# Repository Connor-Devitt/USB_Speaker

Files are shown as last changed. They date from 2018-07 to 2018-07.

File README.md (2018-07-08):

# USB_Speaker
Electro-mechanical design for a  USB spaker

## Electrical Design
* Designed for single cable operation
* USB powered with on-board USB to audio DAC and stereo audio amplifier
* 2 18650 batteries for high power amplifier
* USB charges batteries when speaker is idle

### The Schematic (v0.1)
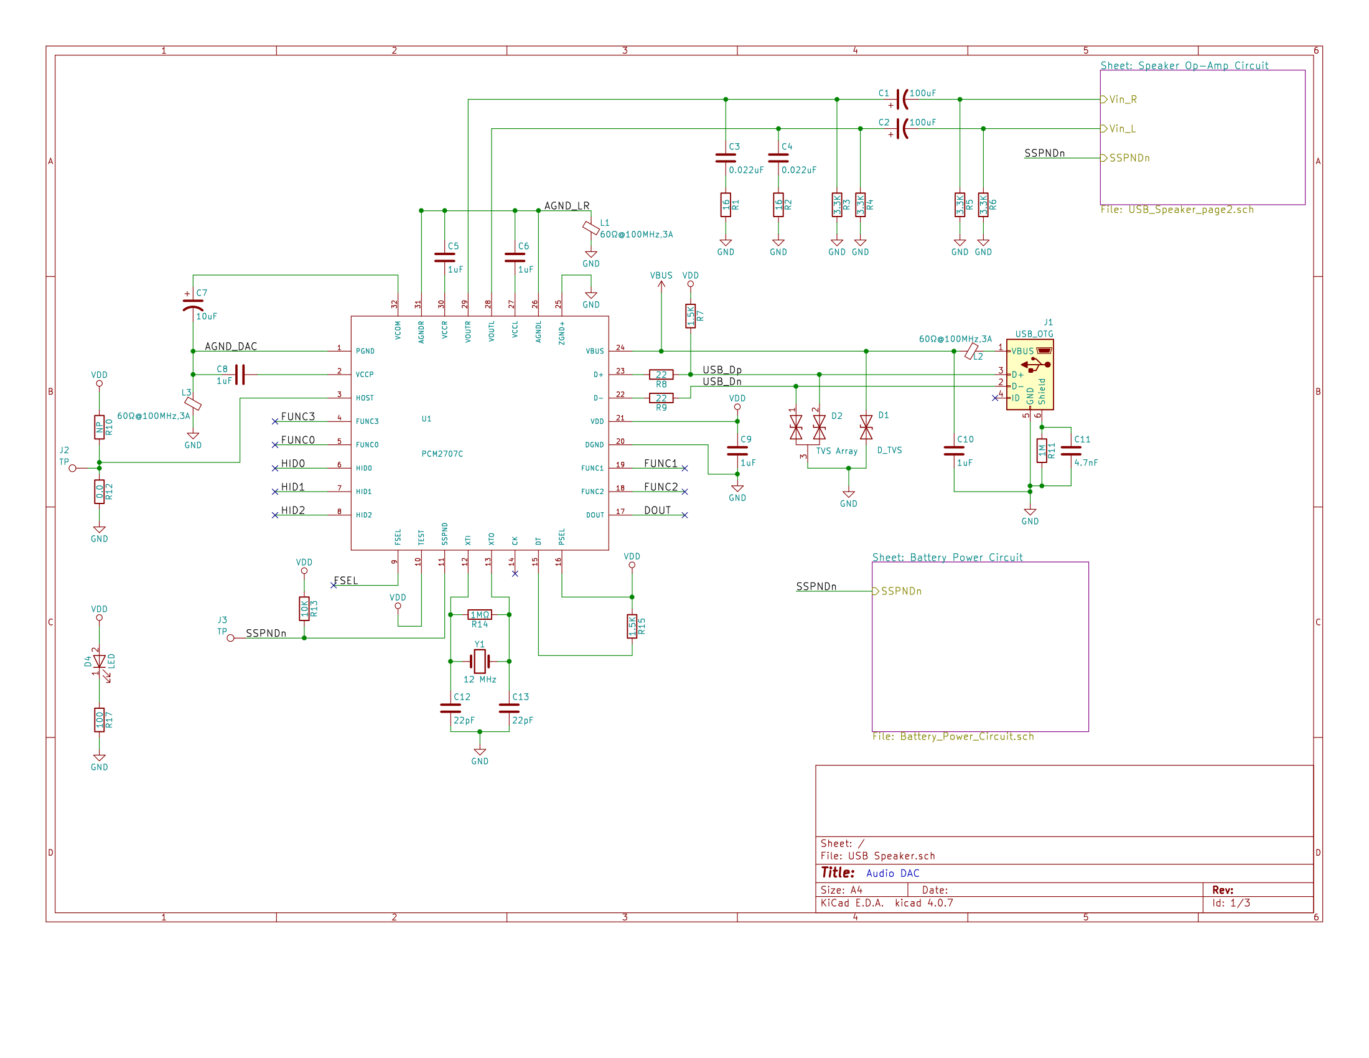
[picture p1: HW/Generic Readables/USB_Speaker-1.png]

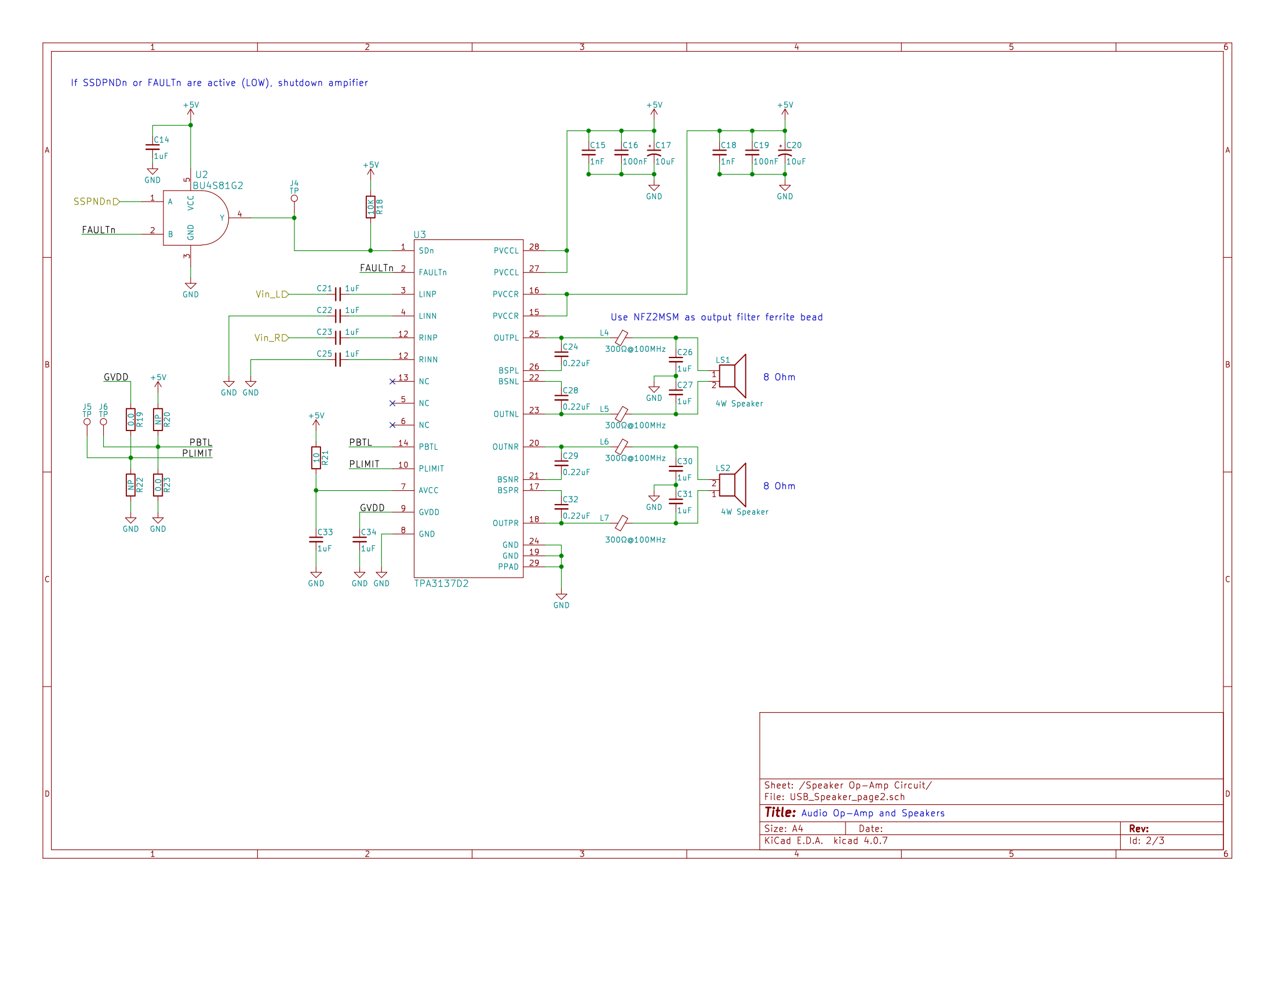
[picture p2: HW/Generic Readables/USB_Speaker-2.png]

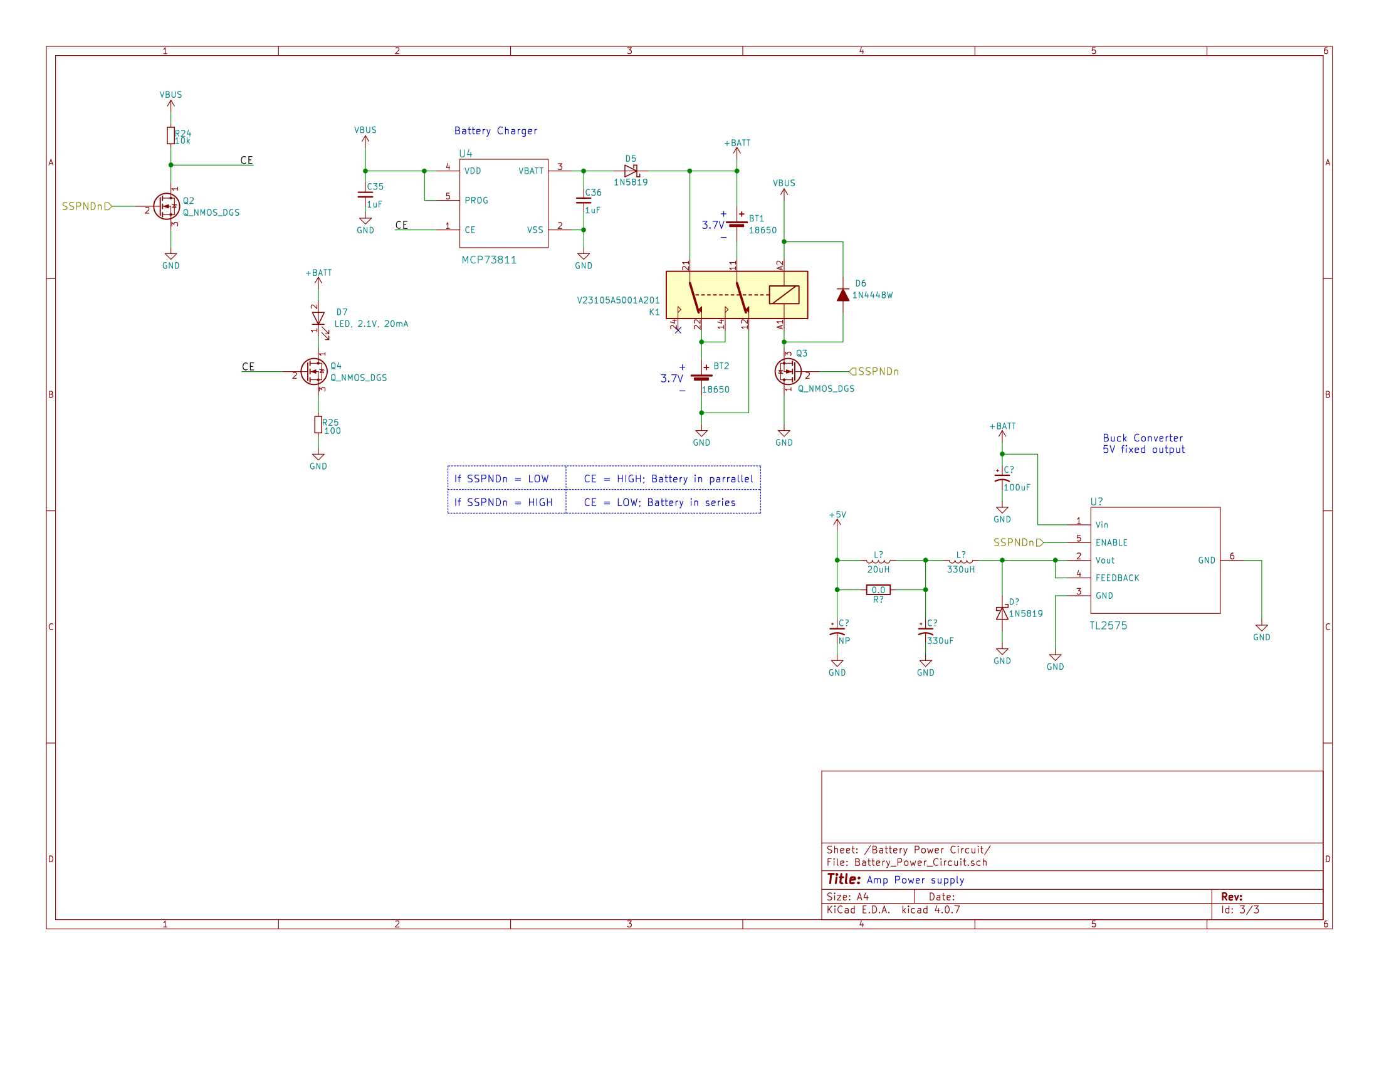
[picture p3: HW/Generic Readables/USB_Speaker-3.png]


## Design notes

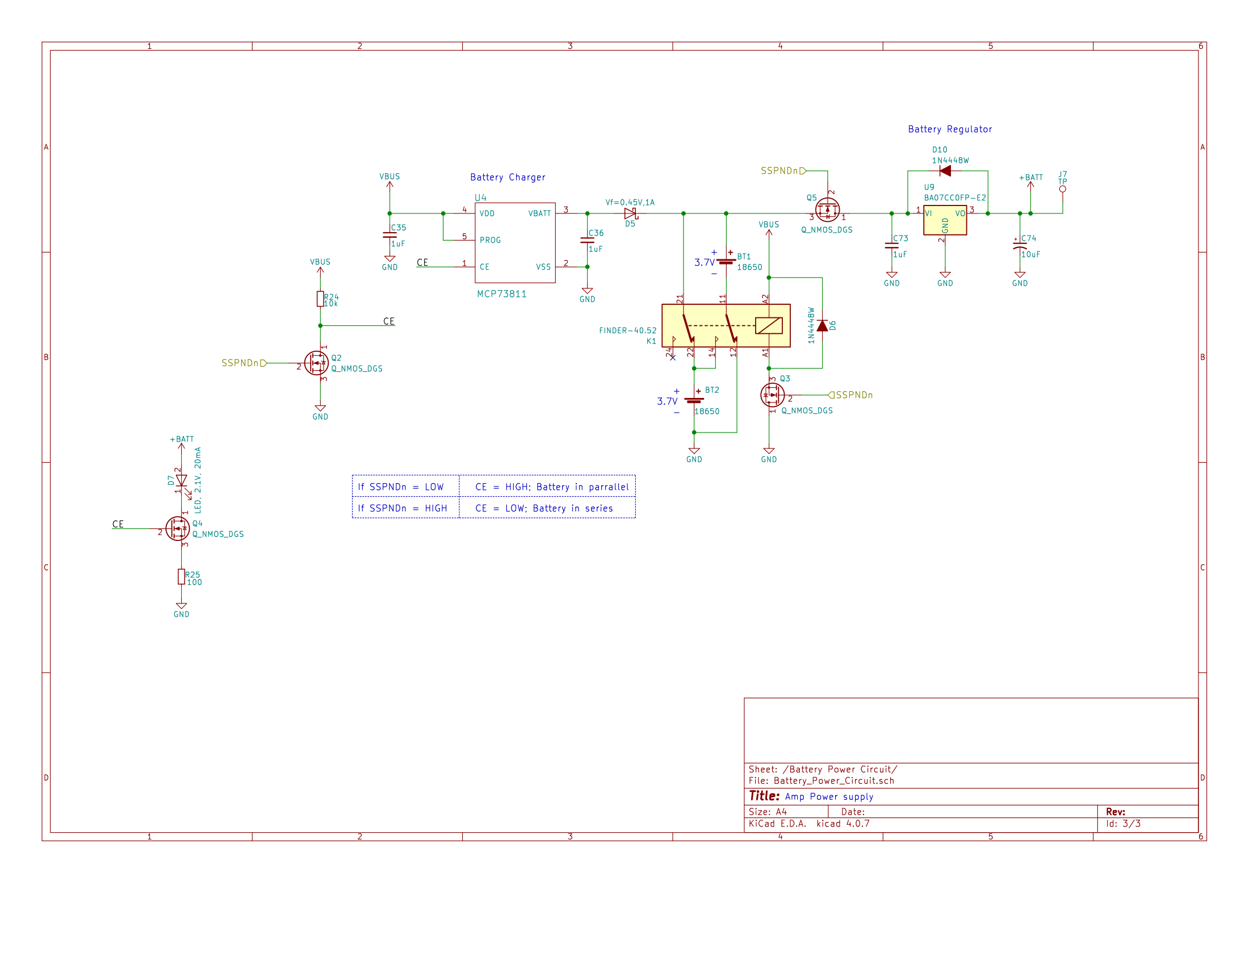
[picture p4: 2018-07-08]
HW/USB_Speaker-3.png

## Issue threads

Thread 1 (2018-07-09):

Battery Saftey

Connor-Devitt, 2018-07-09:
Add over current protection to lipo battery supply

Connor-Devitt, 2018-07-10:
Clarification: Add current monitor IC to *input* of LM2576 and tie output to enable of LM2576.

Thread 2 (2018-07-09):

Power consumption

Connor-Devitt, 2018-07-09:
Change battery regulator to 5V buck converter. Run amplifier off 5V not 7V and use 8-ohm speakers to limit power consumption.

Connor-Devitt, 2018-07-10:
Done.

Closed 2018-07-10.

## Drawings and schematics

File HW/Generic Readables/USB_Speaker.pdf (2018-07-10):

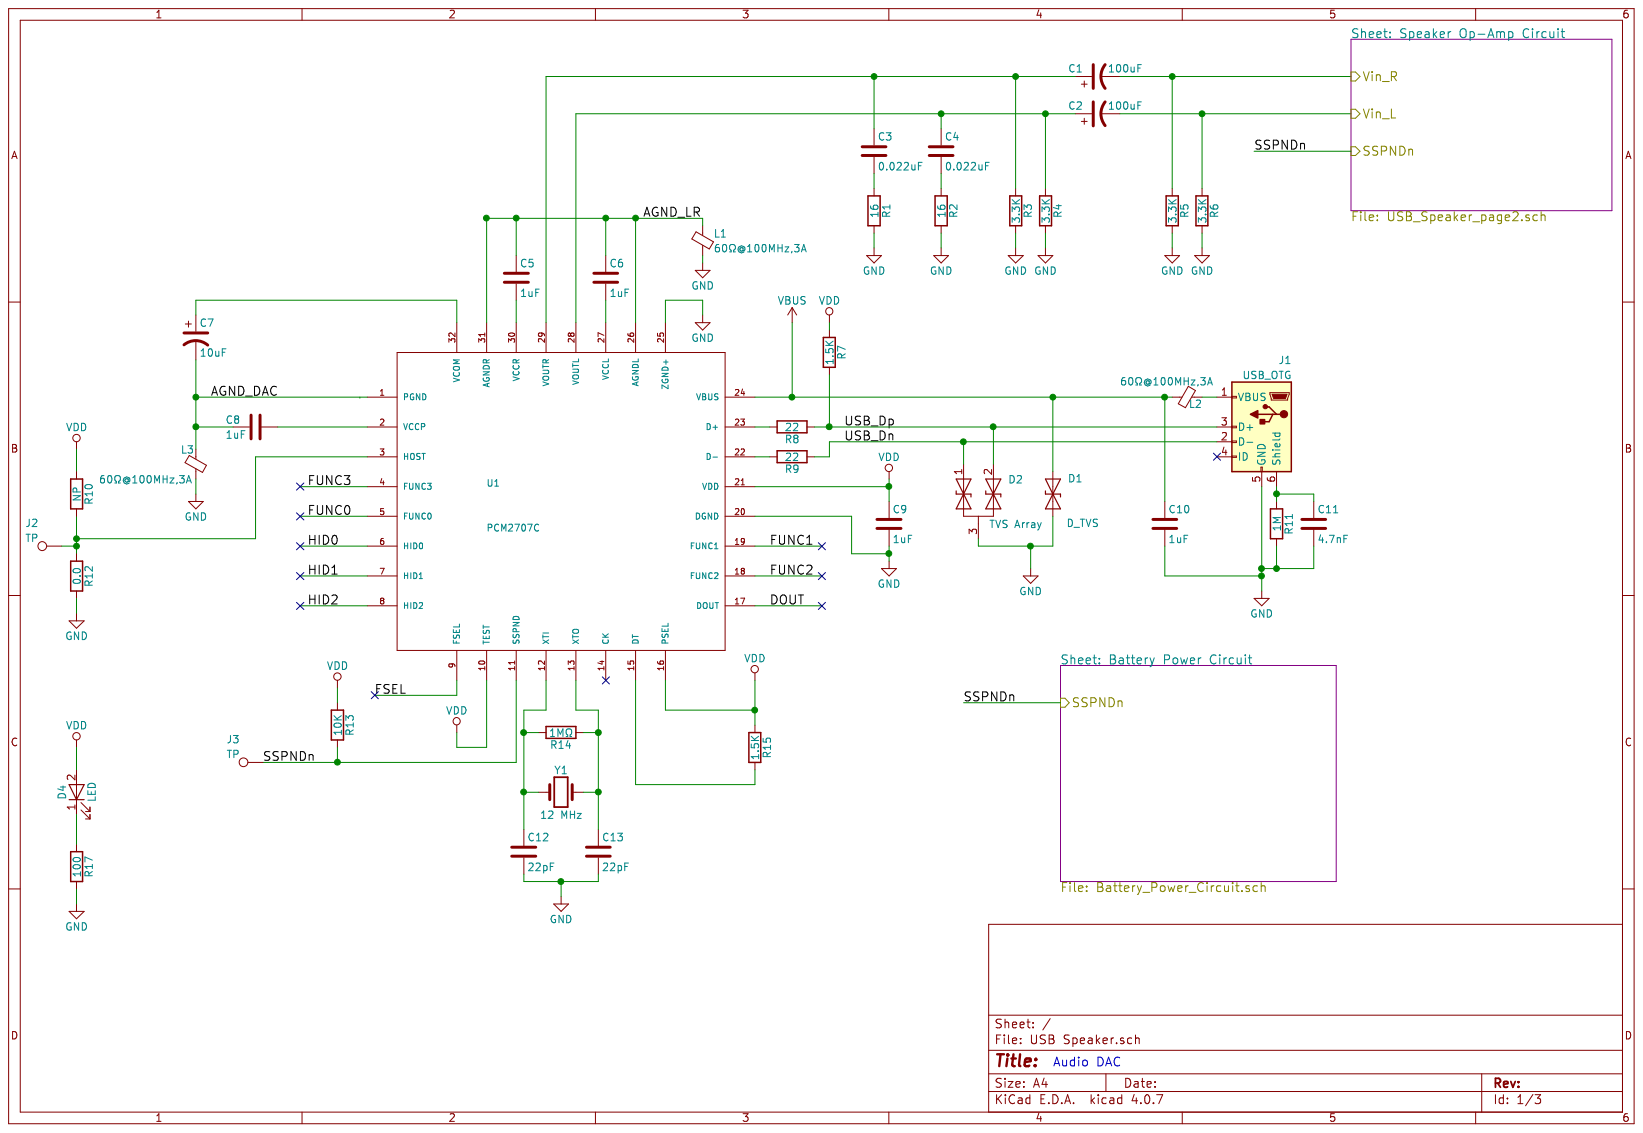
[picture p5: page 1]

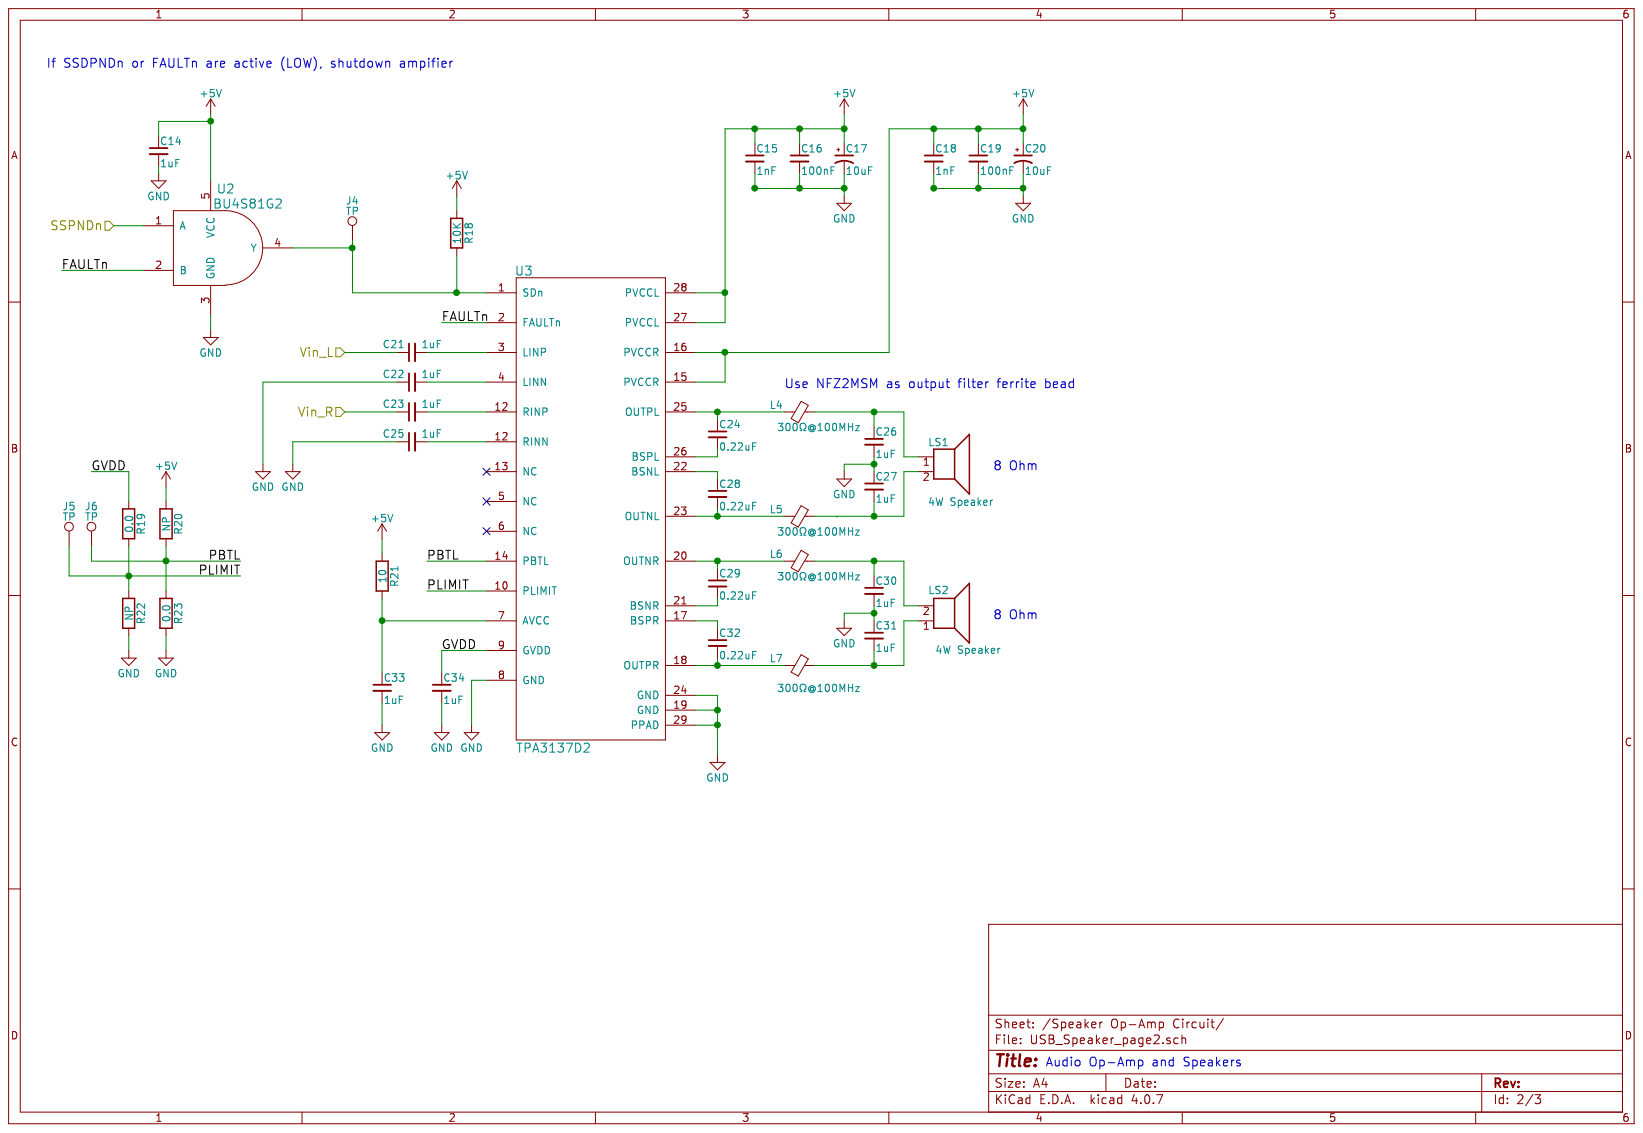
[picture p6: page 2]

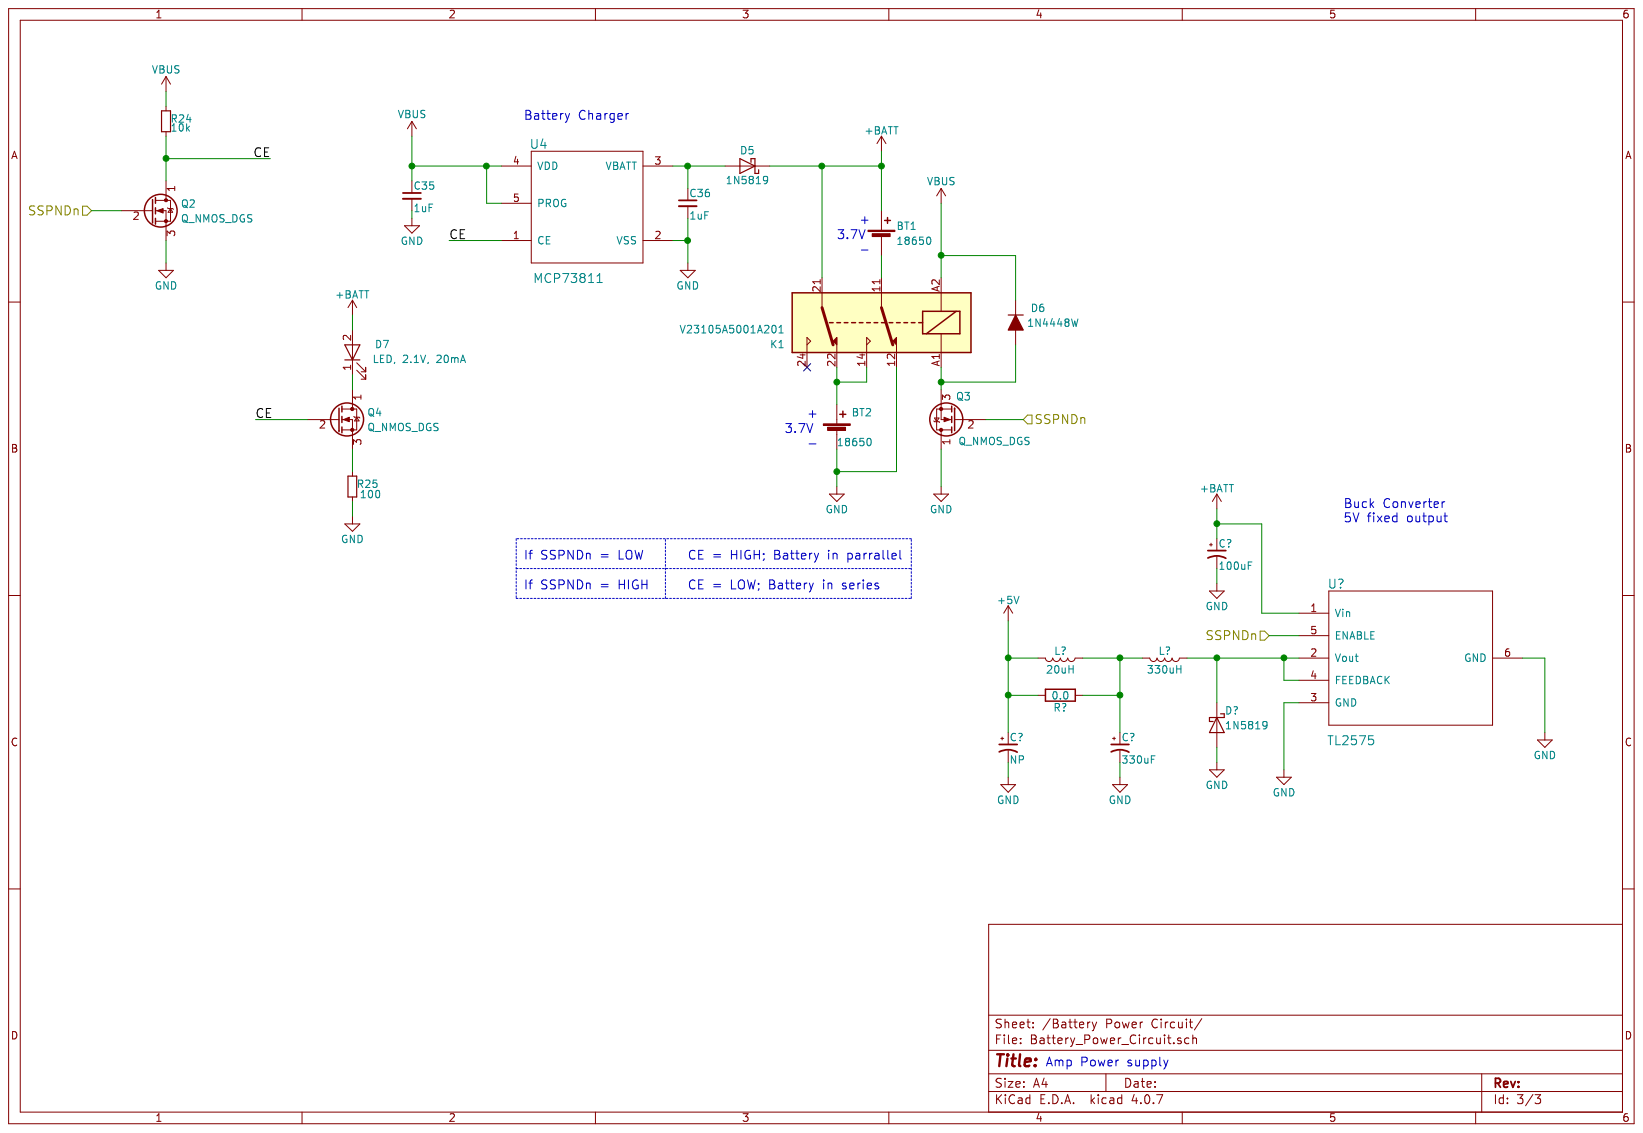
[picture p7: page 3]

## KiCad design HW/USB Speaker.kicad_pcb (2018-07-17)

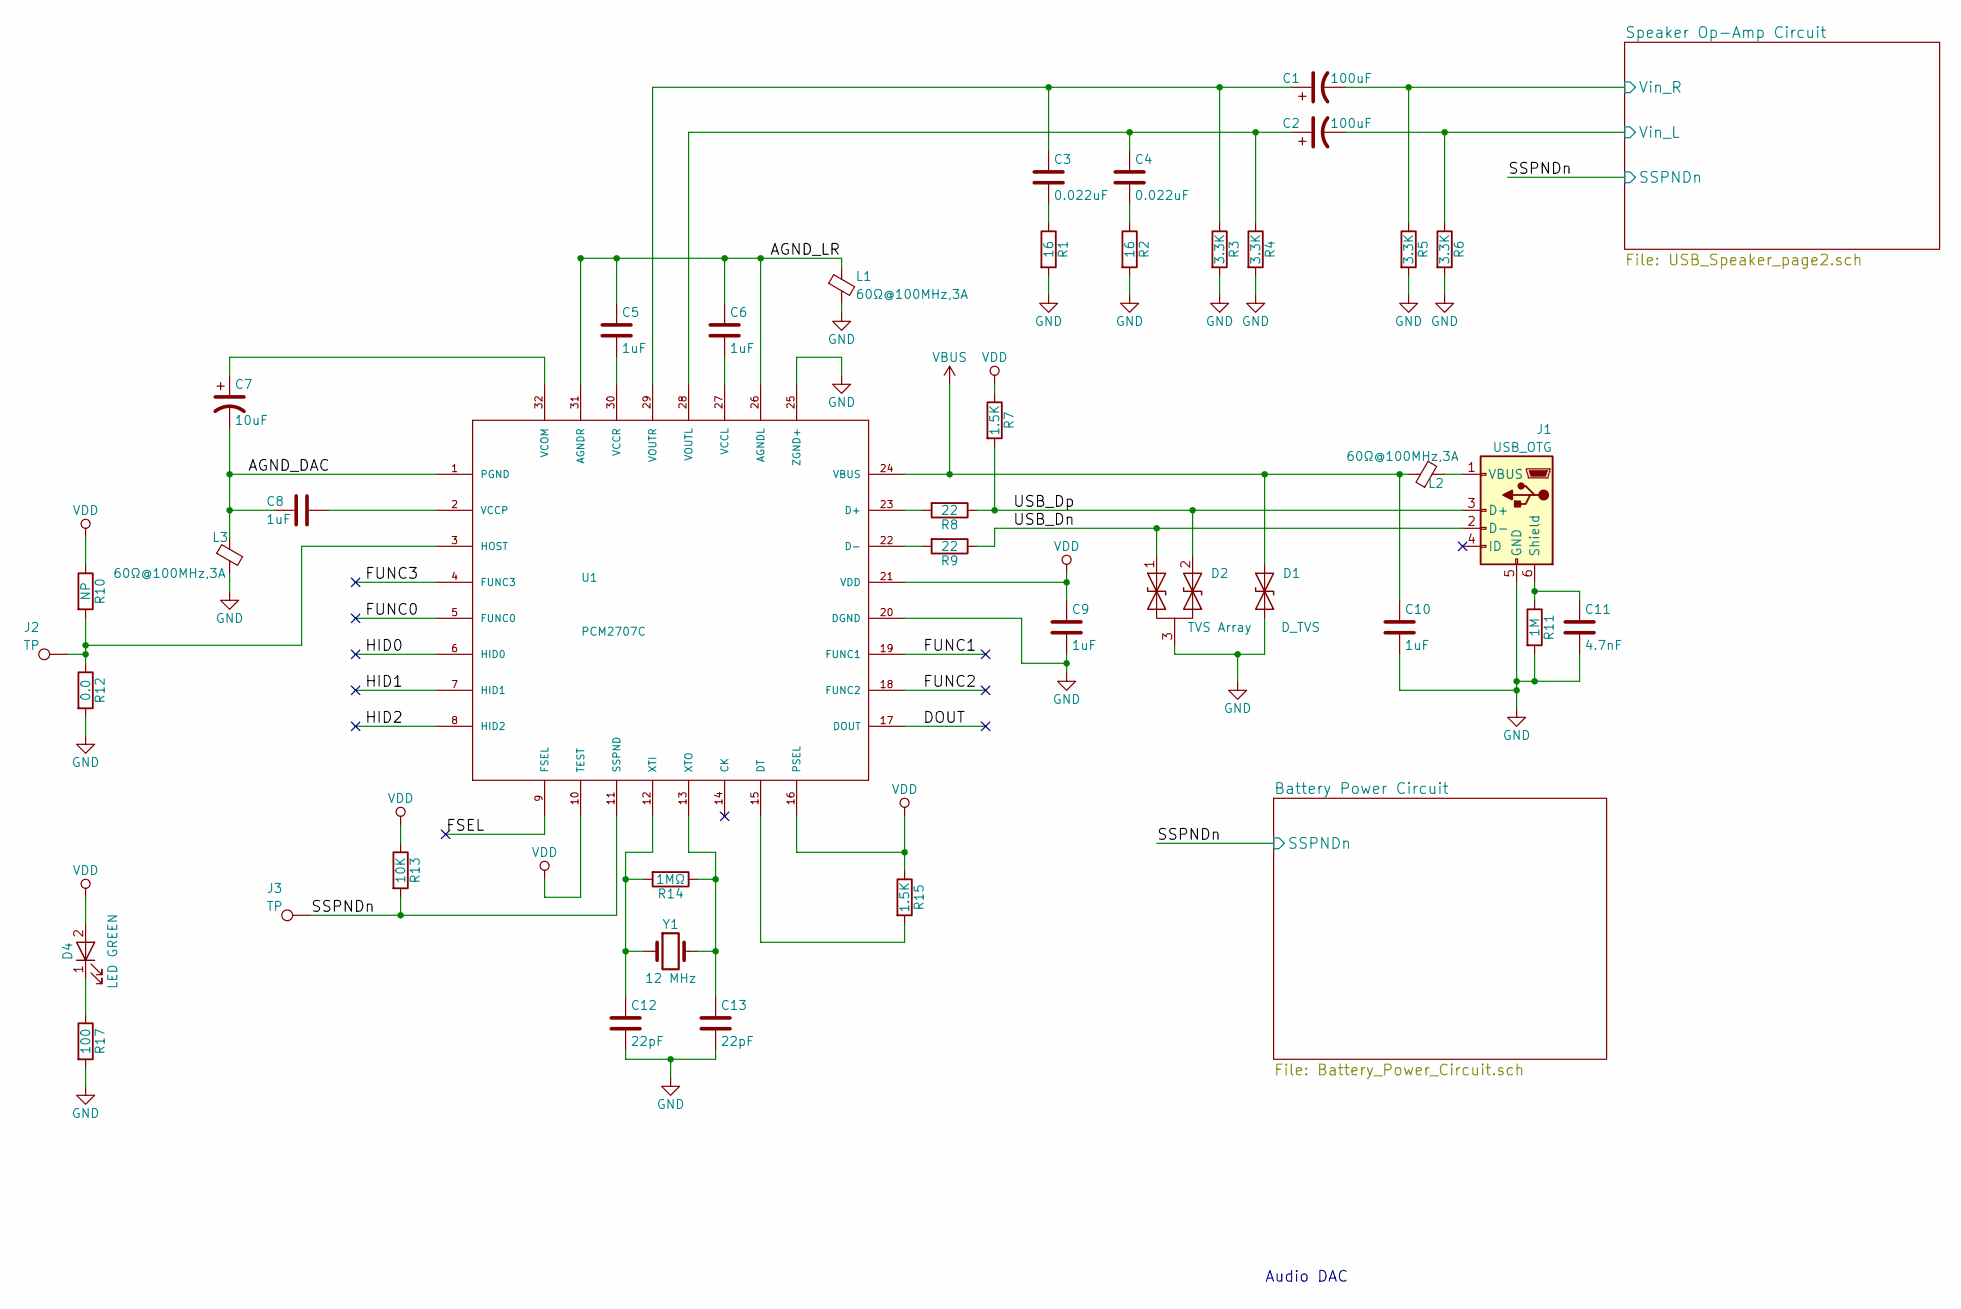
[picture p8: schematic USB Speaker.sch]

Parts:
C1, C2: 100uF; CP_Elec_6.3x5.7
C3, C4: 0.022uF; C_0805_HandSoldering
C5, C6, C8, C9, C10: 1uF; C_0805_HandSoldering
C7: 10uF; CP_Elec_6.3x5.7
C11: 4.7nF; C_0805_HandSoldering
C12, C13: 22pF; C_0805_HandSoldering
D1: D_TVS; D_SC79
D2: TVS Array; SOT-23
D4: LED GREEN; D_0805
J1: USB_OTG; USB_miniB_hirose_5S8
J2, J3: TP; Measurement_Point_Round-TH_Big
L1, L2, L3: 60Ω@100MHz,3A; L_0805_HandSoldering
R1, R2: 16; R_0805_HandSoldering
R3, R4, R5, R6: 3.3K; R_0805_HandSoldering
R7, R15: 1.5K; R_0805_HandSoldering
R8, R9: 22; R_0805_HandSoldering
R10: NP; R_0805_HandSoldering
R11: 1M; R_0805_HandSoldering
R12: 0.0; R_0805_HandSoldering
R13: 10K; R_0805_HandSoldering
R14: 1MΩ; R_0805_HandSoldering
R17: 100; R_0805_HandSoldering
U1: PCM2707C; TQFP-32_7x7mm_Pitch0.8mm
Y1: 12 MHz; Crystal_HC49-4H_Vertical

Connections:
/AGND_DAC: C7.2, C8.2, L3.1, U1.1 (PGND)
/AGND_LR: C5.1, C6.1, L1.1, U1.26 (AGNDL), U1.31 (AGNDR)
/DOUT: U1.17 (DOUT)
/FSEL: U1.9 (FSEL)
/FUNC0: U1.5 (FUNC0)
/FUNC1: U1.19 (FUNC1)
/FUNC2: U1.18 (FUNC2)
/FUNC3: U1.4 (FUNC3)
/HID0: U1.6 (HID0)
/HID1: U1.7 (HID1)
/HID2: U1.8 (HID2)
/SSPNDn: J3.1, R13.2, U1.11 (SSPND); also elsewhere on the board
/Speaker Op-Amp Circuit/Vin_L: C2.2, R6.1; also elsewhere on the board
/Speaker Op-Amp Circuit/Vin_R: C1.2, R5.1; also elsewhere on the board
/USB_Dn: D2.1 (A1), J1.2 (D-), R9.1
/USB_Dp: D2.2 (A2), J1.3 (D+), R7.2, R8.1
GND: C9.2, C10.2, C11.2, C12.2, C13.2, D1.1 (A1), D2.3 (common), J1.5 (GND), L1.2, L3.2, R1.2, R2.2, R3.2, R4.2, R5.2, R6.2, R11.2, R12.2, R17.2, U1.20 (DGND), U1.25 (ZGND+); also elsewhere on the board
unnamed: C1.1, C3.1, R3.1, U1.29 (VOUTR)
unnamed: C2.1, C4.1, R4.1, U1.28 (VOUTL)
unnamed: C3.2, R1.1
unnamed: C4.2, R2.1
unnamed: C5.2, U1.30 (VCCR)
unnamed: C6.2, U1.27 (VCCL)
unnamed: C7.1, U1.32 (VCOM)
unnamed: C8.1, U1.2 (VCCP)
unnamed: C11.1, J1.6 (Shield), R11.1
unnamed: C12.1, R14.2, U1.12 (XTI), Y1.1
unnamed: C13.1, R14.1, U1.13 (XTO), Y1.2
unnamed: D4.1 (K), R17.1
unnamed: J1.1 (VBUS), L2.2
unnamed: J2.1, R10.2, R12.1, U1.3 (HOST)
unnamed: R8.2, U1.23 (D+)
unnamed: R9.2, U1.22 (D-)
unnamed: R15.2, U1.15 (DT)
VBUS: C10.1, D1.2 (A2), L2.1, U1.24 (VBUS); also elsewhere on the board
VDD: C9.1, D4.2 (A), R7.1, R10.1, R13.1, R15.1, U1.10 (TEST), U1.16 (PSEL), U1.21 (VDD)

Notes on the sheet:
Audio DAC

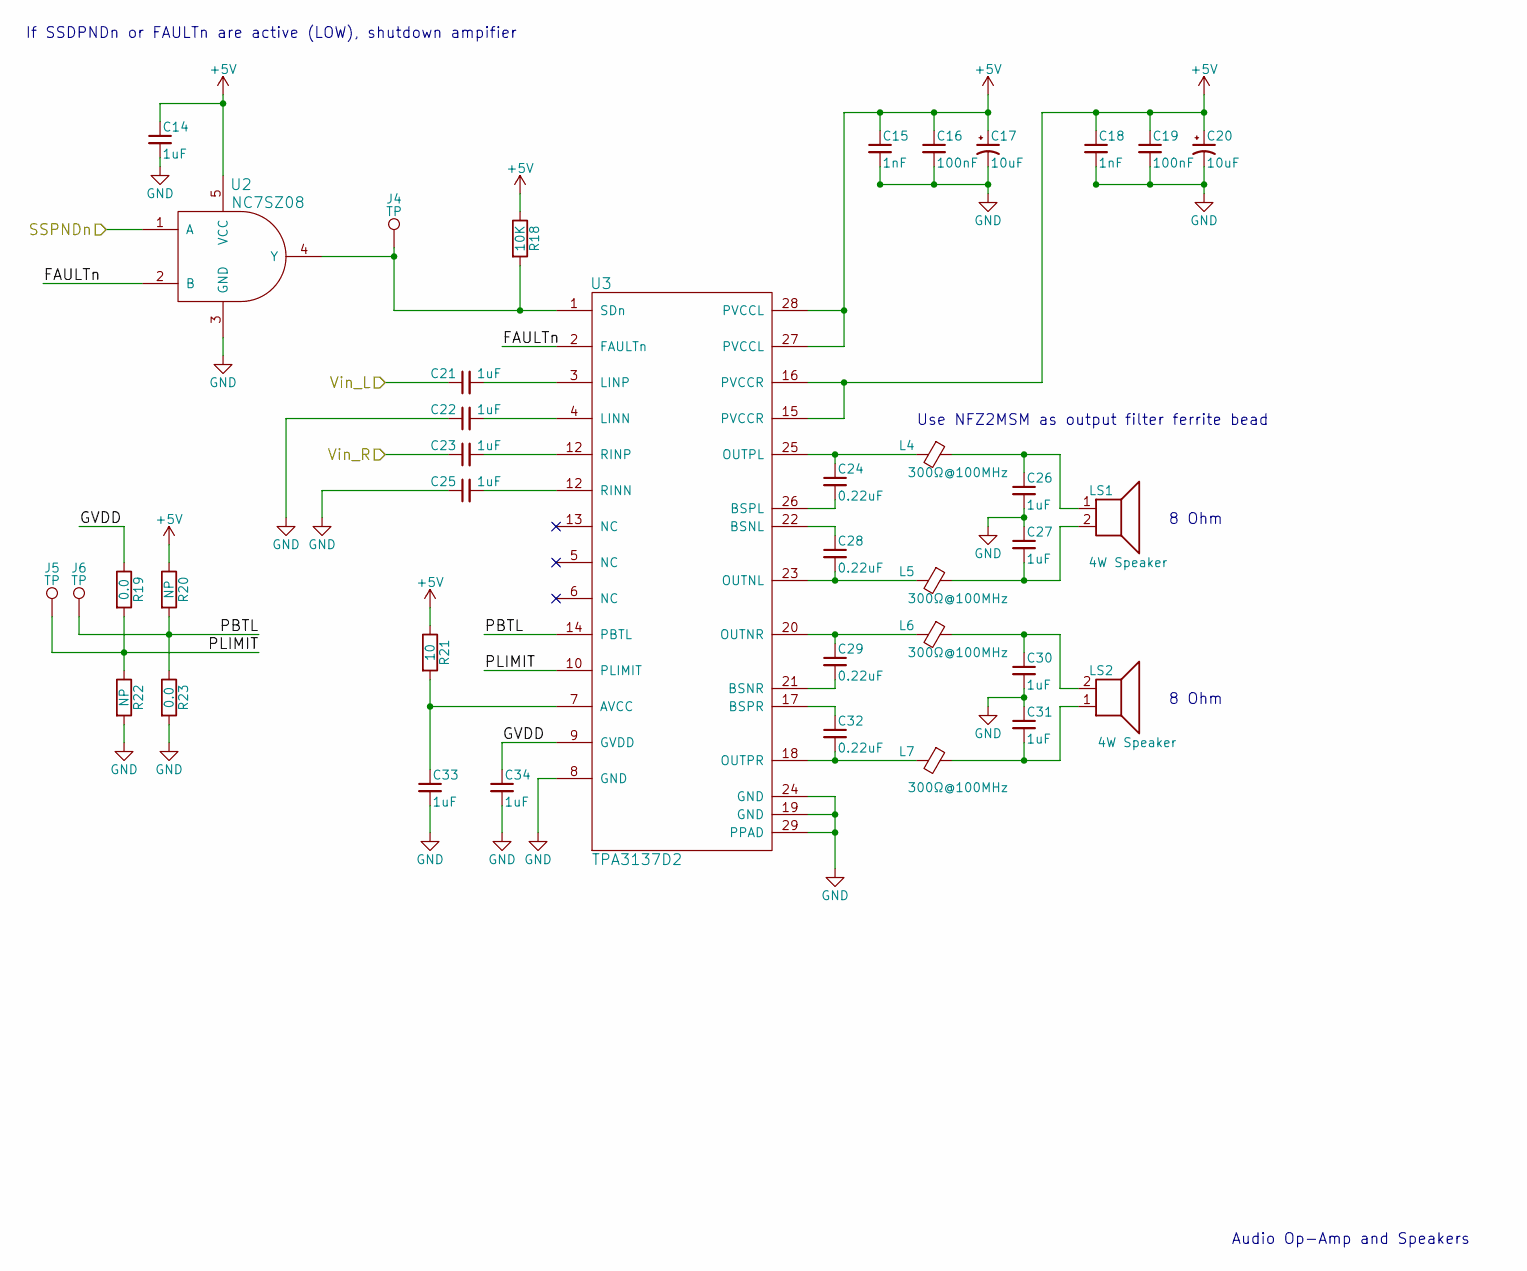
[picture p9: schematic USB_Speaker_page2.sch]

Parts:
C14, C21, C22, C23, C25, C26, C27, C30, C31, C33, C34: 1uF; C_0805_HandSoldering
C15, C18: 1nF; C_0805_HandSoldering
C16, C19: 100nF; C_0805_HandSoldering
C17, C20: 10uF; CP_Elec_6.3x5.7
C24, C28, C29, C32: 0.22uF; C_0805_HandSoldering
J4, J5, J6: TP; Measurement_Point_Round-TH_Big
L4, L5, L6, L7: 300Ω@100MHz; L_0805_HandSoldering
LS1, LS2: 4W Speaker; TerminalBlock_bornier-2_P5.08mm
R18: 10K; R_0805_HandSoldering
R19, R23: 0.0; R_0805_HandSoldering
R20, R22: NP; R_0805_HandSoldering
R21: 10; R_0805_HandSoldering
U2: NC7SZ08; SOT-23-5_HandSoldering
U3: TPA3137D2; TSSOP-28_4.4x9.7mm_Pitch0.65mm

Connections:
+5V: C14.1, C15.1, C16.1, C17.1, C18.1, C19.1, C20.1, R18.1, R20.1, R21.1, U2.5 (VCC), U3.15 (PVCCR), U3.16 (PVCCR), U3.27 (PVCCL), U3.28 (PVCCL); also elsewhere on the board
/SSPNDn: U2.1 (A); also elsewhere on the board
/Speaker Op-Amp Circuit/FAULTn: U2.2 (B), U3.2 (FAULTn)
/Speaker Op-Amp Circuit/GVDD: C34.1, R19.1, U3.9 (GVDD)
/Speaker Op-Amp Circuit/PBTL: J6.1, R20.2, R23.1, U3.14 (PBTL)
/Speaker Op-Amp Circuit/PLIMIT: J5.1, R19.2, R22.1, U3.10 (PLIMIT)
/Speaker Op-Amp Circuit/Vin_L: C21.1; also elsewhere on the board
/Speaker Op-Amp Circuit/Vin_R: C23.1; also elsewhere on the board
GND: C14.2, C15.2, C16.2, C17.2, C18.2, C19.2, C20.2, C22.1, C25.1, C26.2, C27.1, C30.2, C31.1, C33.2, C34.2, R22.2, R23.2, U2.3 (GND), U3.8 (GND), U3.19 (GND), U3.24 (GND), U3.29 (PPAD); also elsewhere on the board
unnamed: C21.2, U3.3 (LINP)
unnamed: C22.2, U3.4 (LINN)
unnamed: C24.1, L4.2, U3.25 (OUTPL)
unnamed: C24.2, U3.26 (BSPL)
unnamed: C26.1, L4.1, LS1.1
unnamed: C27.2, L5.1, LS1.2
unnamed: C28.1, U3.22 (BSNL)
unnamed: C28.2, L5.2, U3.23 (OUTNL)
unnamed: C29.1, L6.2, U3.20 (OUTNR)
unnamed: C29.2, U3.21 (BSNR)
unnamed: C30.1, L6.1, LS2.2
unnamed: C31.2, L7.1, LS2.1
unnamed: C32.1, U3.17 (BSPR)
unnamed: C32.2, L7.2, U3.18 (OUTPR)
unnamed: C33.1, R21.2, U3.7 (AVCC)
unnamed: J4.1, R18.2, U2.4 (Y), U3.1 (SDn)

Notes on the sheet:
Audio Op-Amp and Speakers
Use NFZ2MSM as output filter ferrite bead
If SSDPNDn or FAULTn are active (LOW), shutdown ampifier
8 Ohm

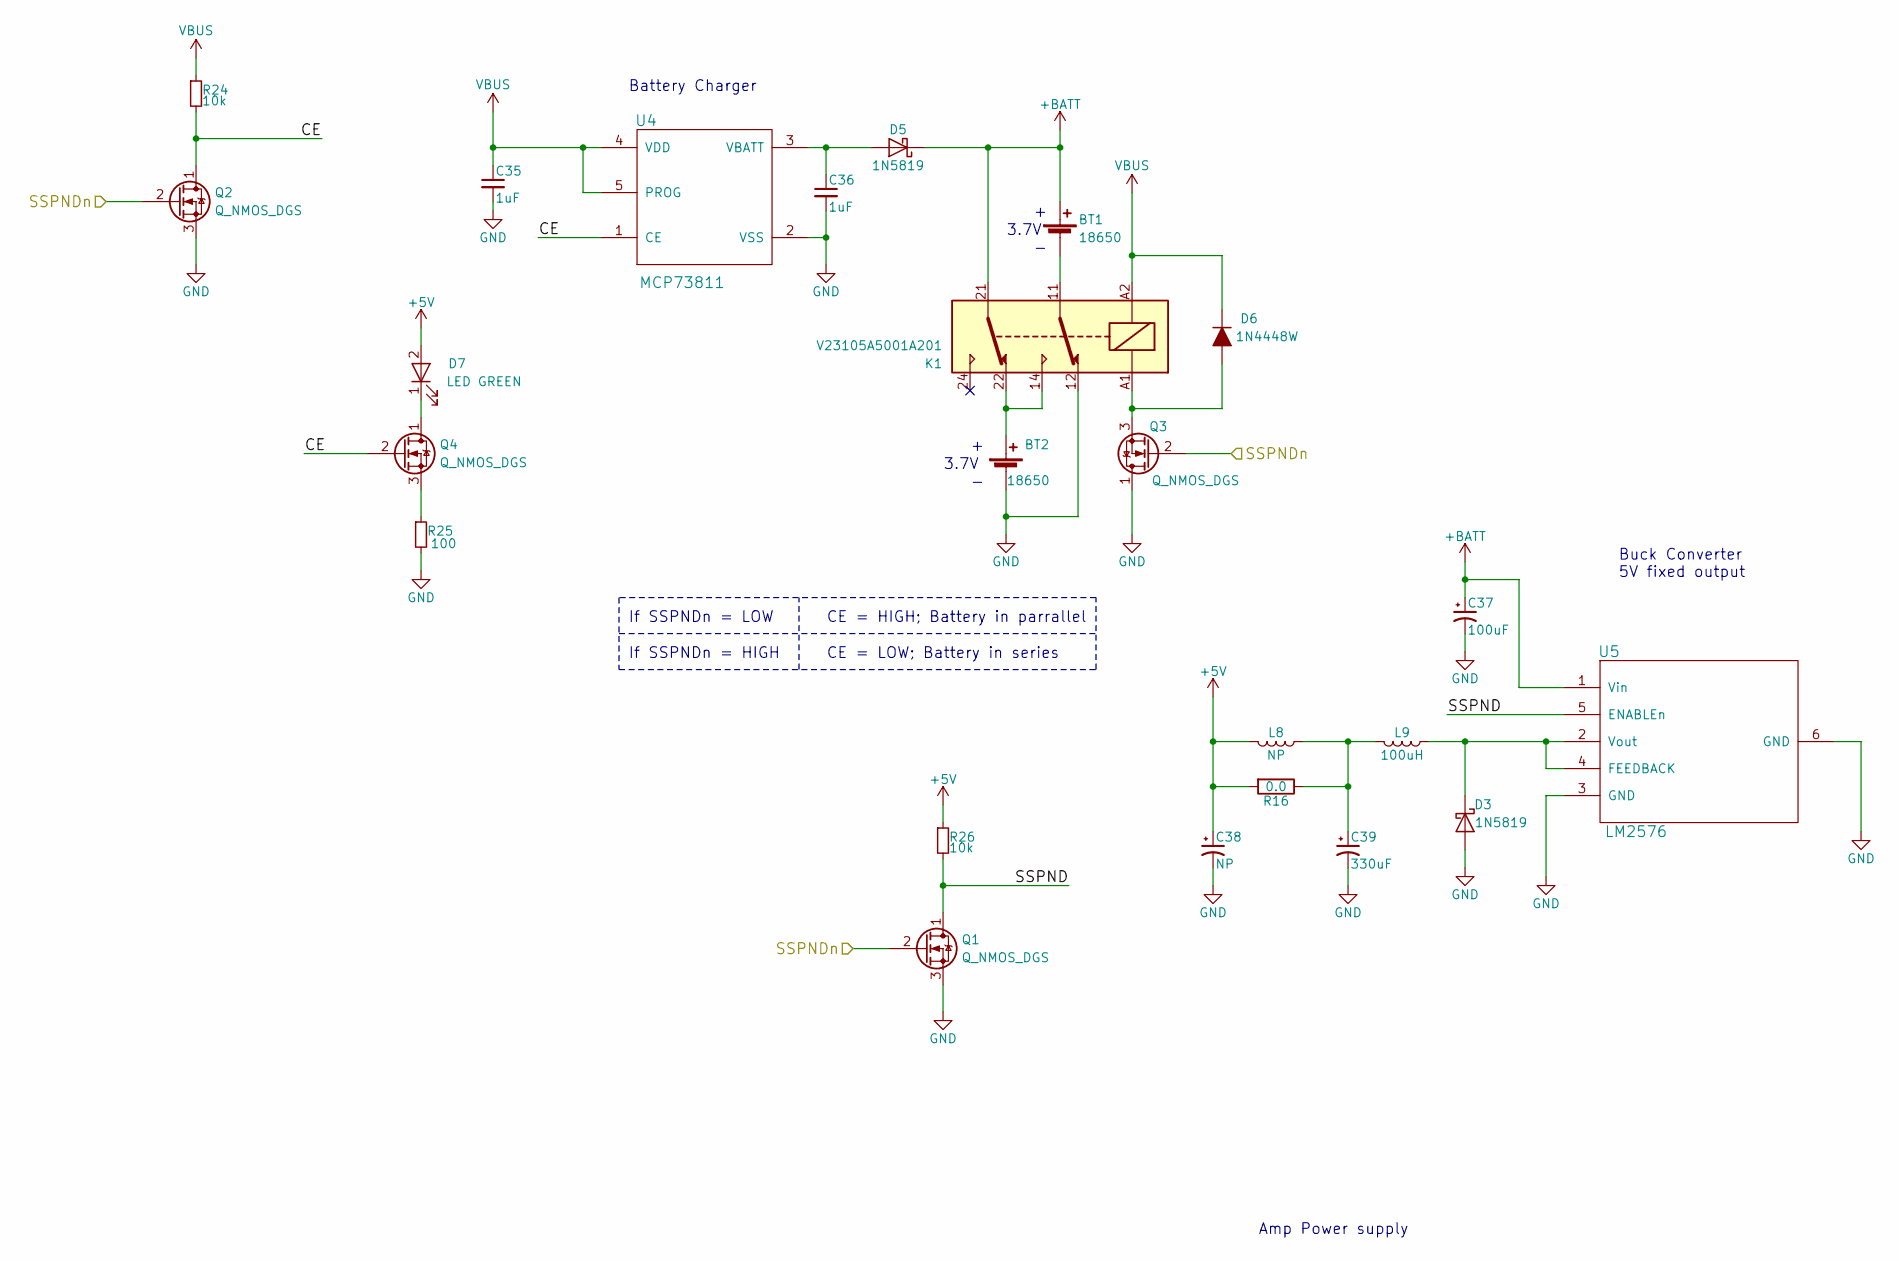
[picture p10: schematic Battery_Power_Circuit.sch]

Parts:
BT1, BT2: 18650; TerminalBlock_bornier-2_P5.08mm
C35, C36: 1uF; C_0805_HandSoldering
C37: 100uF; CP_Elec_6.3x5.7
C38: NP; CP_Elec_6.3x5.7
C39: 330uF; CP_Elec_6.3x7.7
D3, D5: 1N5819; D_SOD-123
D6: 1N4448W; D_SOD-123
D7: LED GREEN; D_0805
K1: V23105A5001A201; Relay_DPDT_Finder_40.52
L8: NP; L_12x12mm_h4.5mm
L9: 100uH; L_12x12mm_h8mm
Q1, Q2, Q3, Q4: Q_NMOS_DGS; SOT-23_Handsoldering
R16: 0.0; R_0805_HandSoldering
R24, R26: 10k; R_0805_HandSoldering
R25: 100; R_0805_HandSoldering
U4: MCP73811; SOT-23-5_HandSoldering
U5: LM2576; TO-263-5_TabPin6

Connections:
+5V: C38.1, D7.2 (A), L8.2, R16.2, R26.1; also elsewhere on the board
+BATT: BT1.1 (+), C37.1, D5.1 (K), K1.21, U5.1 (Vin)
/Battery Power Circuit/CE: Q2.1 (D), Q4.2 (G), R24.2, U4.1 (CE)
/Battery Power Circuit/SSPND: Q1.1 (D), R26.2, U5.5 (ENABLEn)
/SSPNDn: Q1.2 (G), Q2.2 (G), Q3.2 (G); also elsewhere on the board
GND: BT2.2 (-), C35.2, C36.2, C37.2, C38.2, C39.2, D3.2 (A), K1.12, Q1.3 (S), Q2.3 (S), Q3.1 (D), R25.2, U4.2 (VSS), U5.3 (GND), U5.6 (GND); also elsewhere on the board
unnamed: BT1.2 (-), K1.11
unnamed: BT2.1 (+), K1.14, K1.22
unnamed: C36.1, D5.2 (A), U4.3 (VBATT)
unnamed: C39.1, L8.1, L9.2, R16.1
unnamed: D3.1 (K), L9.1, U5.2 (Vout), U5.4 (FEEDBACK)
unnamed: D6.2 (A), K1.A1, Q3.3 (S)
unnamed: D7.1 (K), Q4.1 (D)
unnamed: Q4.3 (S), R25.1
VBUS: C35.1, D6.1 (K), K1.A2, R24.1, U4.4 (VDD), U4.5 (PROG); also elsewhere on the board

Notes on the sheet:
Amp Power supply
If SSPNDn = LOW
If SSPNDn = HIGH
CE = HIGH; Battery in parrallel
CE = LOW; Battery in series
3.7V
Battery Charger
Buck Converter 5V fixed output

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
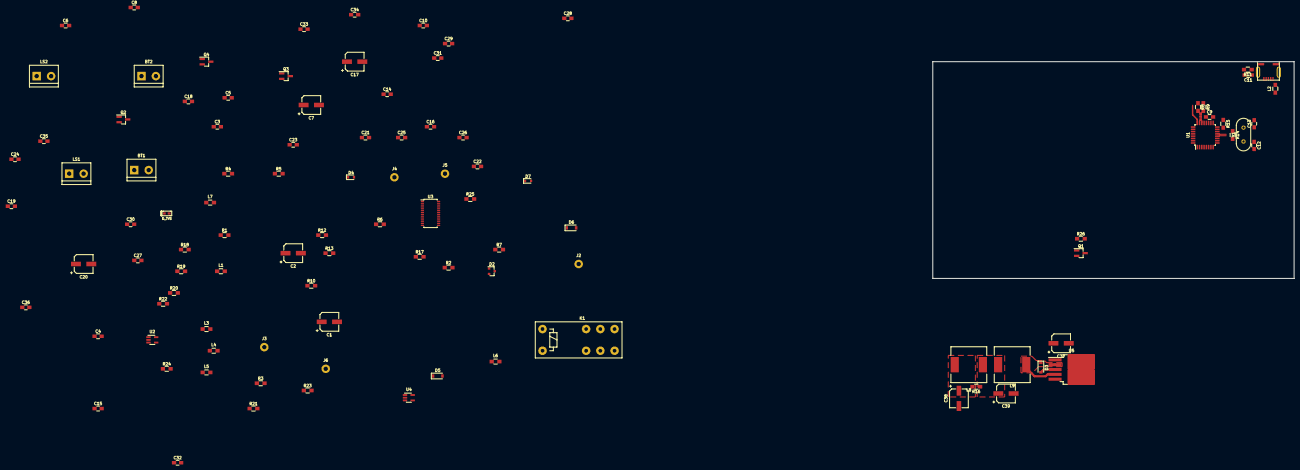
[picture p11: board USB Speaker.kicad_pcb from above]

Board: 2 copper layers, 127.0 x 76.2 mm, 102 parts (0 on the bottom side), 60 nets.

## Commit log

2018-06-07 Clock and USB circuits
    [USB Speaker.sch]
2018-06-09 DAC circuit
    [USB Speaker.sch]
2018-06-14 DAC circuit edits and op-amp symbol creation
    [USB Speaker.sch, USB_Speaker_page2.sch]
2018-06-19 Amplifier circuit using TPA6211A1-Q1
    [USB Speaker.sch, USB_Speaker_page2.sch]
2018-06-20 Switching out 2x TPA6211A1 for 1x TPA3137D2
    [USB Speaker.sch, USB_Speaker_page2.sch]
2018-06-21 Finsihed drawing amp circuit. Adding options and values later
    [USB Speaker.sch, USB_Speaker_page2.sch]
2018-06-24 ferrite chosen
    [USB Speaker.sch, USB_Speaker_page2.sch]
2018-06-27 Basic battery power supply topology
    [Bettery_Power_Circuit.sch, USB Speaker.sch, USB_Speaker_page2.sch]
2018-06-28 What did I do?
    [Battery_Power_Circuit.sch, Bettery_Power_Circuit.sch, USB Speaker.sch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]
2018-07-04 Added LEDs, Test points, and ESD protection on USB
    [Battery_Power_Circuit.sch, USB Speaker.sch, USB_Speaker_page2.sch]
2018-07-08 First draft done :100:
    [Battery_Power_Circuit.sch, USB Speaker.sch, USB_DAC.sch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]
2018-07-08 Added schematic in png form
2018-07-08 First :b:raft 4realz :100:
    [USB Speaker.sch, USB_Speaker_page2.sch]
2018-07-08 Deleted an empty page
    [USB Speaker.sch]
2018-07-10 7V Regulator now a 5V buck converter
    [Battery_Power_Circuit.sch, USB Speaker.sch, USB_Speaker_page2.sch]
2018-07-10 Buck and fp
    Changed buck to one with 3A output. Started fp association
    [Battery_Power_Circuit.sch, USB Speaker.sch, USB_Speaker_page2.sch]
2018-07-17 parts association and some selection
    [Battery_Power_Circuit.sch, USB Speaker.sch, USB_Speaker_page2.sch]
2018-07-17 initial layout
    [USB Speaker.kicad_pcb]
